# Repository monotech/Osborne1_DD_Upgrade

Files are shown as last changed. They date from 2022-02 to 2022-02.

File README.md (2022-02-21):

# Osborne1_DD_Upgrade
Exact replica of the Double Density floppy upgrade board for the Osborne 1

Every part except the PCB can be bought from proper distributors such as Mouser, Digikey, Farnell/element14, LCSC, etc. Avoid chips from Aliexpress/eBay.

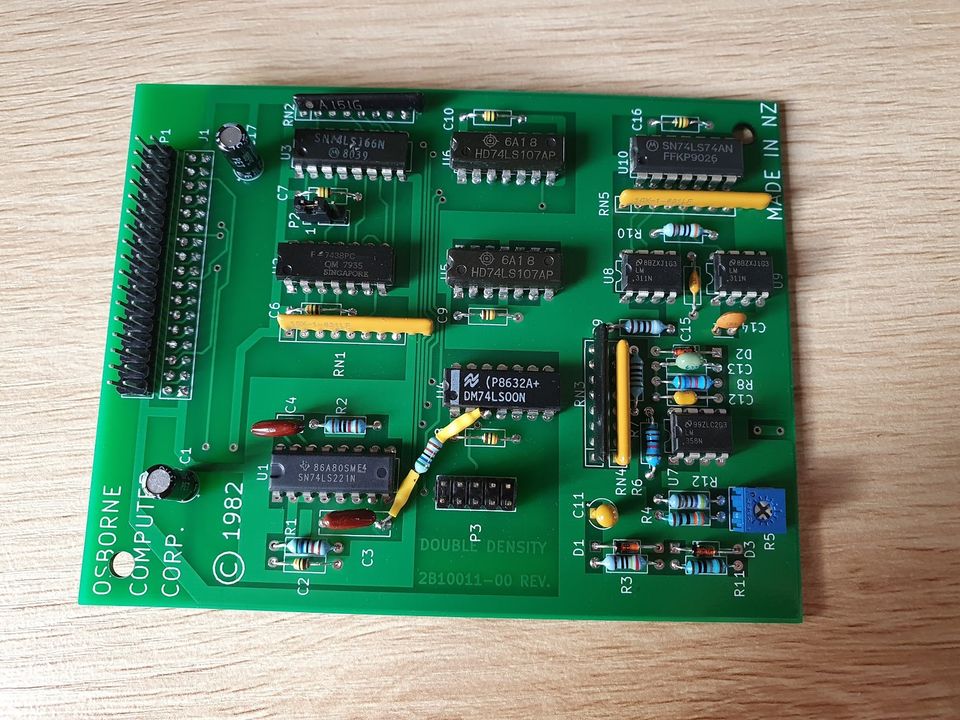
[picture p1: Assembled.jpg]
assembled


Licensed under CC BY-SA 4.0 (https://creativecommons.org/licenses/by-sa/4.0/)

You can share, change, sell, but you must give credit and provide your adaptations under the same license.

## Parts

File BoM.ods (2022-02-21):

Designator | Quantity | Part | Package | Notes
 | 1 | PCB
 | 1 | 2x5 2.54mm IDC cable | 18cm
 | 1 | 2.54mm jumper shunt
P1 | 1 | 2x17 2.54mm male header
J1 | 1 | 2x17 2.54mm female header
P2 | 1 | 1x3 2.54mm male header
P3 | 1 | 2x5 2.54mm male header
C1 | 1 | 22uF 16V Electrolytic | 2.54mm
C17 | 1 | 47uF 16V Electrolytic | 2.54mm
C11 | 1 | 1uF 16V Tantalum | 2.54mm
C12 | 1 | 330pF ceramic capacitor | 10.16mm axial
C13 | 1 | 3.3nF ceramic capacitor | 10.16mm axial
C15 | 1 | 100nF ceramic capacitor | 10.16mm axial
C14 | 1 | 47pF ceramic capacitor | 2.54mm
C3-4 | 2 | 47pF 2% mica capacitor | 2.54mm
C2,C6-10,C16 | 7 | 10nF ceramic capacitor | 10.16mm axial
D1 | 1 | 1N5231B | 10.16mm axial
D2 | 1 | 1N5228B | 10.16mm axial
D3 | 1 | 1N5238 | 10.16mm axial
RN1,RN5 | 2 | 820R 7-way bussed resistor network | SIP-8
RN2 | 1 | 150R 7-way bussed resistor network | SIP-8 | SIP-5 is fine also
RN3 | 1 | 4.7k 7-way bussed resistor network | SIP-8 | SIP-5 is fine also
RN4 | 1 | 39k 4-way isolated resistor pack | SIP-8
R1,bodge1 | 2 | 56.2k 1% resistor | 10.16mm axial
bodge2 | 1 | 1M resistor
R2 | 1 | 10k 1% resistor | 10.16mm axial
R3 | 1 | 240R resistor | 10.16mm axial
R4 | 1 | 330R 1% resistor | 10.16mm axial
R5 | 1 | 10k trimpot | T73YP
R6 | 1 | 11k resistor | 10.16mm axial
R7 | 1 | 510R resistor | 10.16mm axial
R8 | 1 | 16k resistor | 10.16mm axial
R9 | 1 | 9.1k 2% resistor | 10.16mm axial
R10 | 1 | 3.01k 1% resistor | 10.16mm axial
R11 | 1 | 180R resistor | 10.16mm axial
R12 | 1 | 4.7k 2% resistor | 10.16mm axial
U1 | 1 | 74LS221 IC | DIP-16
U2 | 1 | 7438 IC | DIP-14
U3 | 1 | 74LS166 IC | DIP-16
U4 | 1 | 74LS00 IC | DIP-14
U5-6 | 2 | 74LS107 IC | DIP-14
U7 | 1 | LM358 IC | DIP-8
U8-9 | 2 | LM311 IC | DIP-8
U10 | 1 | 74LS74 IC | DIP-14
 |  |  | TP9 is U7 Pin7.

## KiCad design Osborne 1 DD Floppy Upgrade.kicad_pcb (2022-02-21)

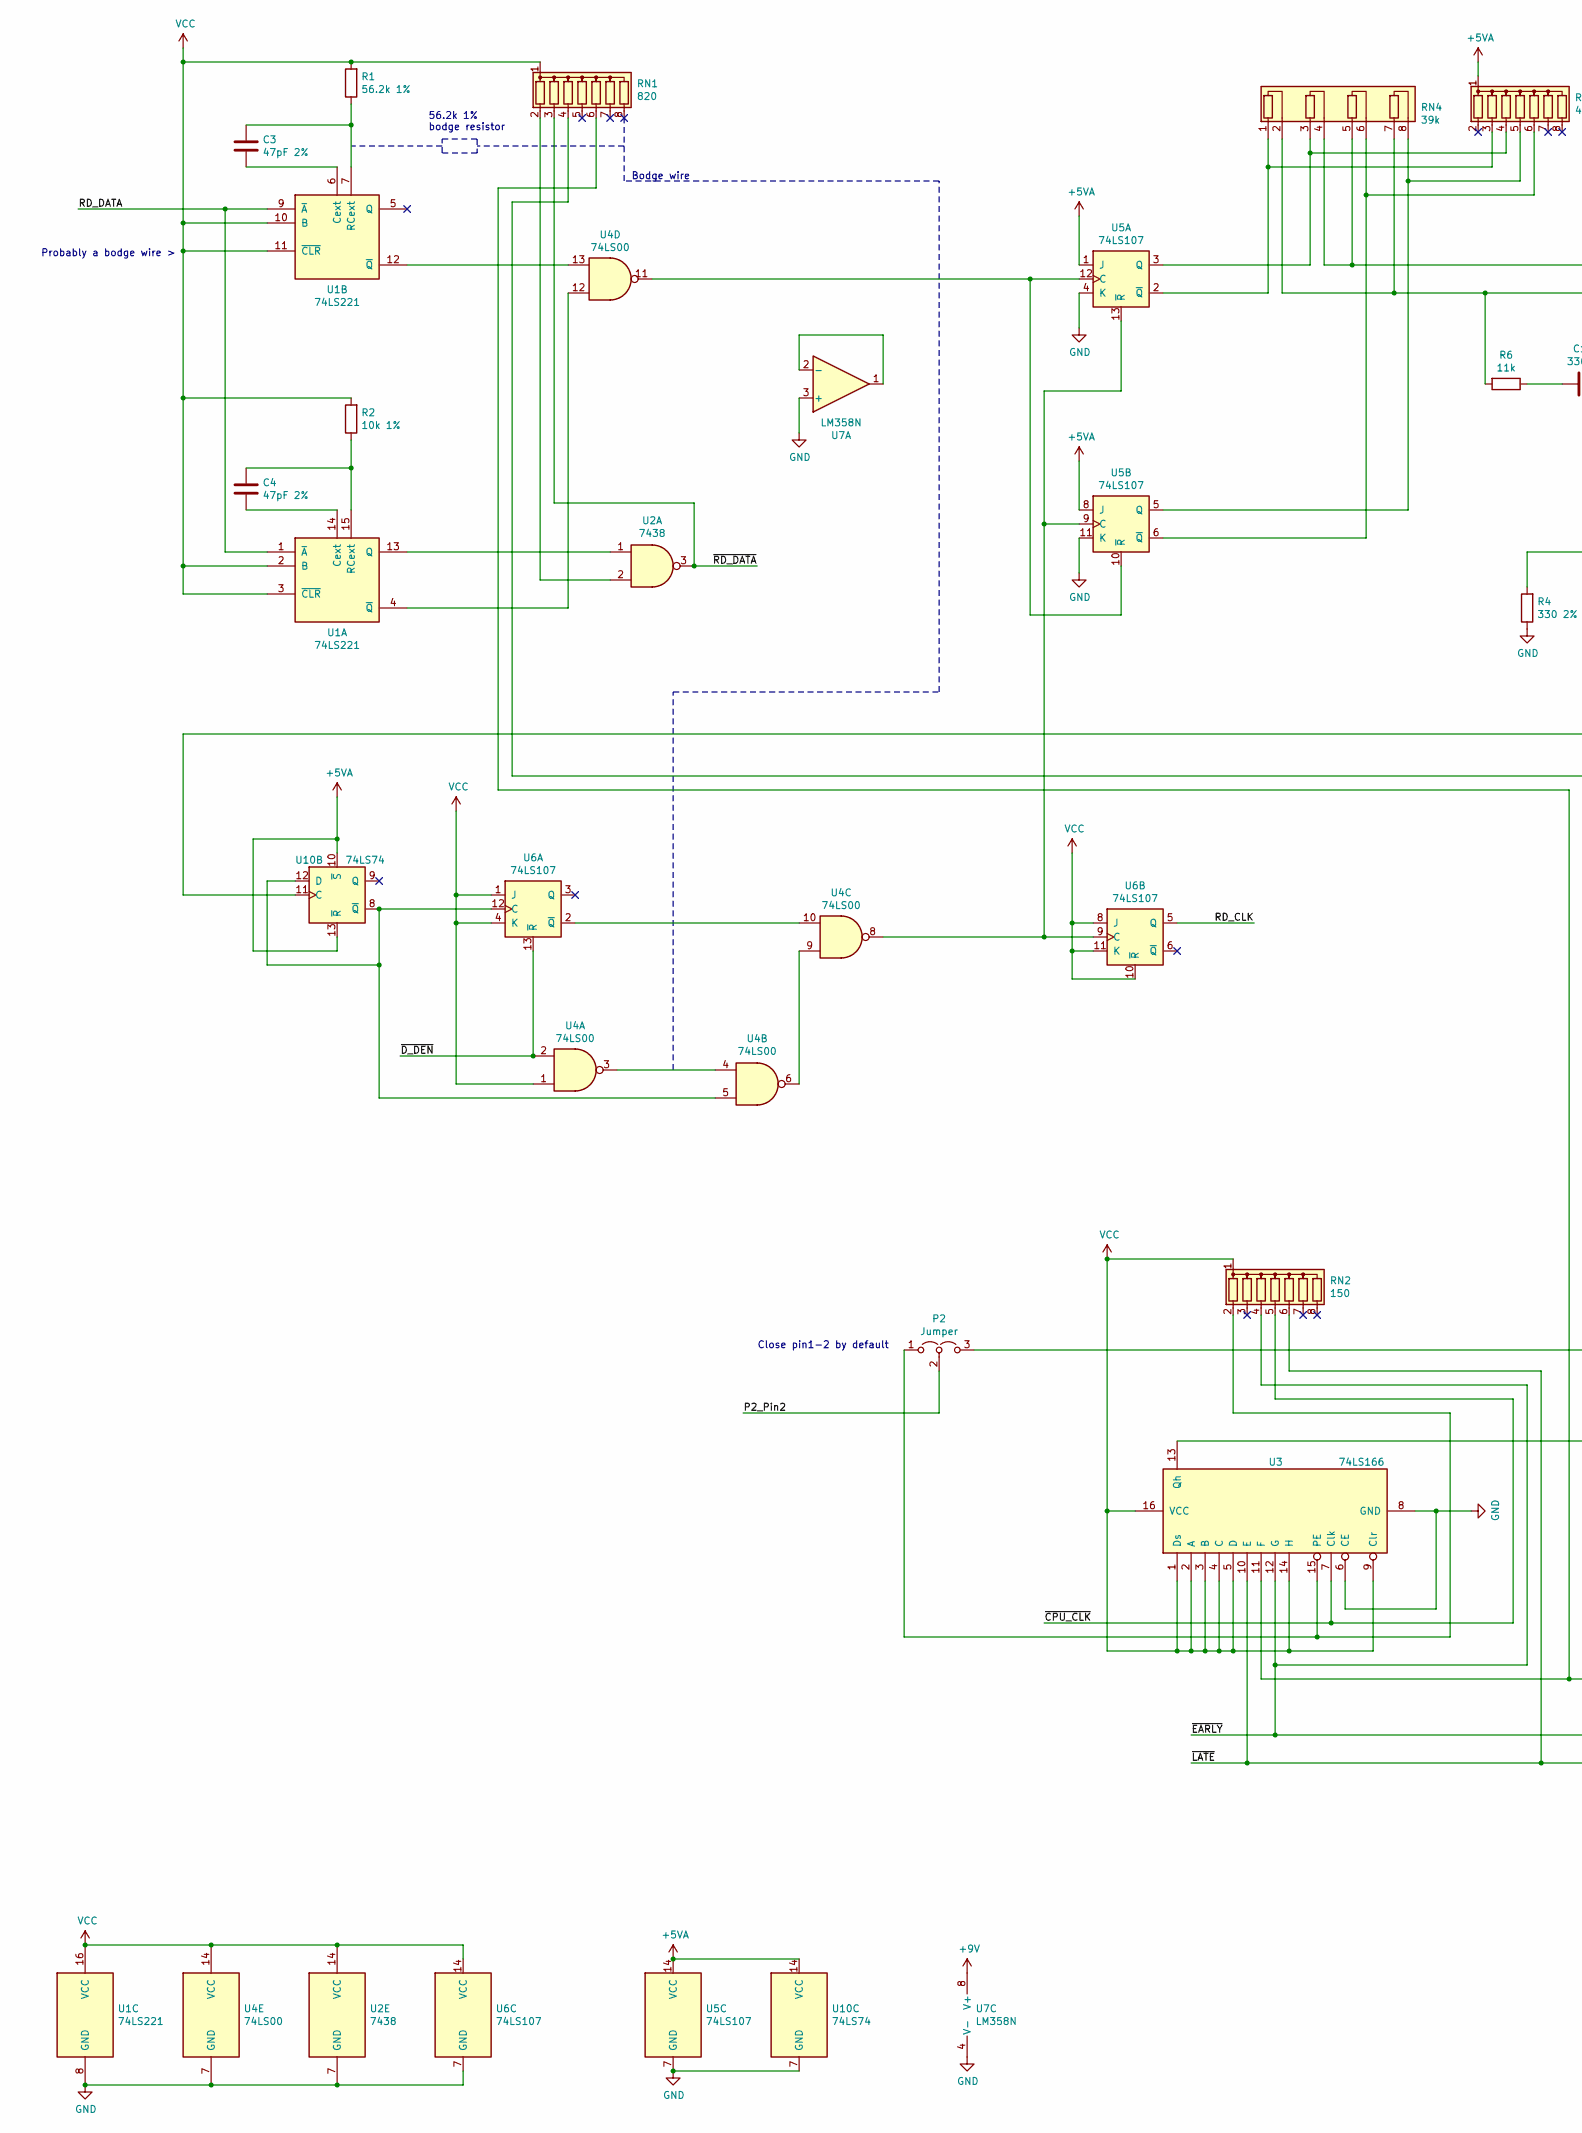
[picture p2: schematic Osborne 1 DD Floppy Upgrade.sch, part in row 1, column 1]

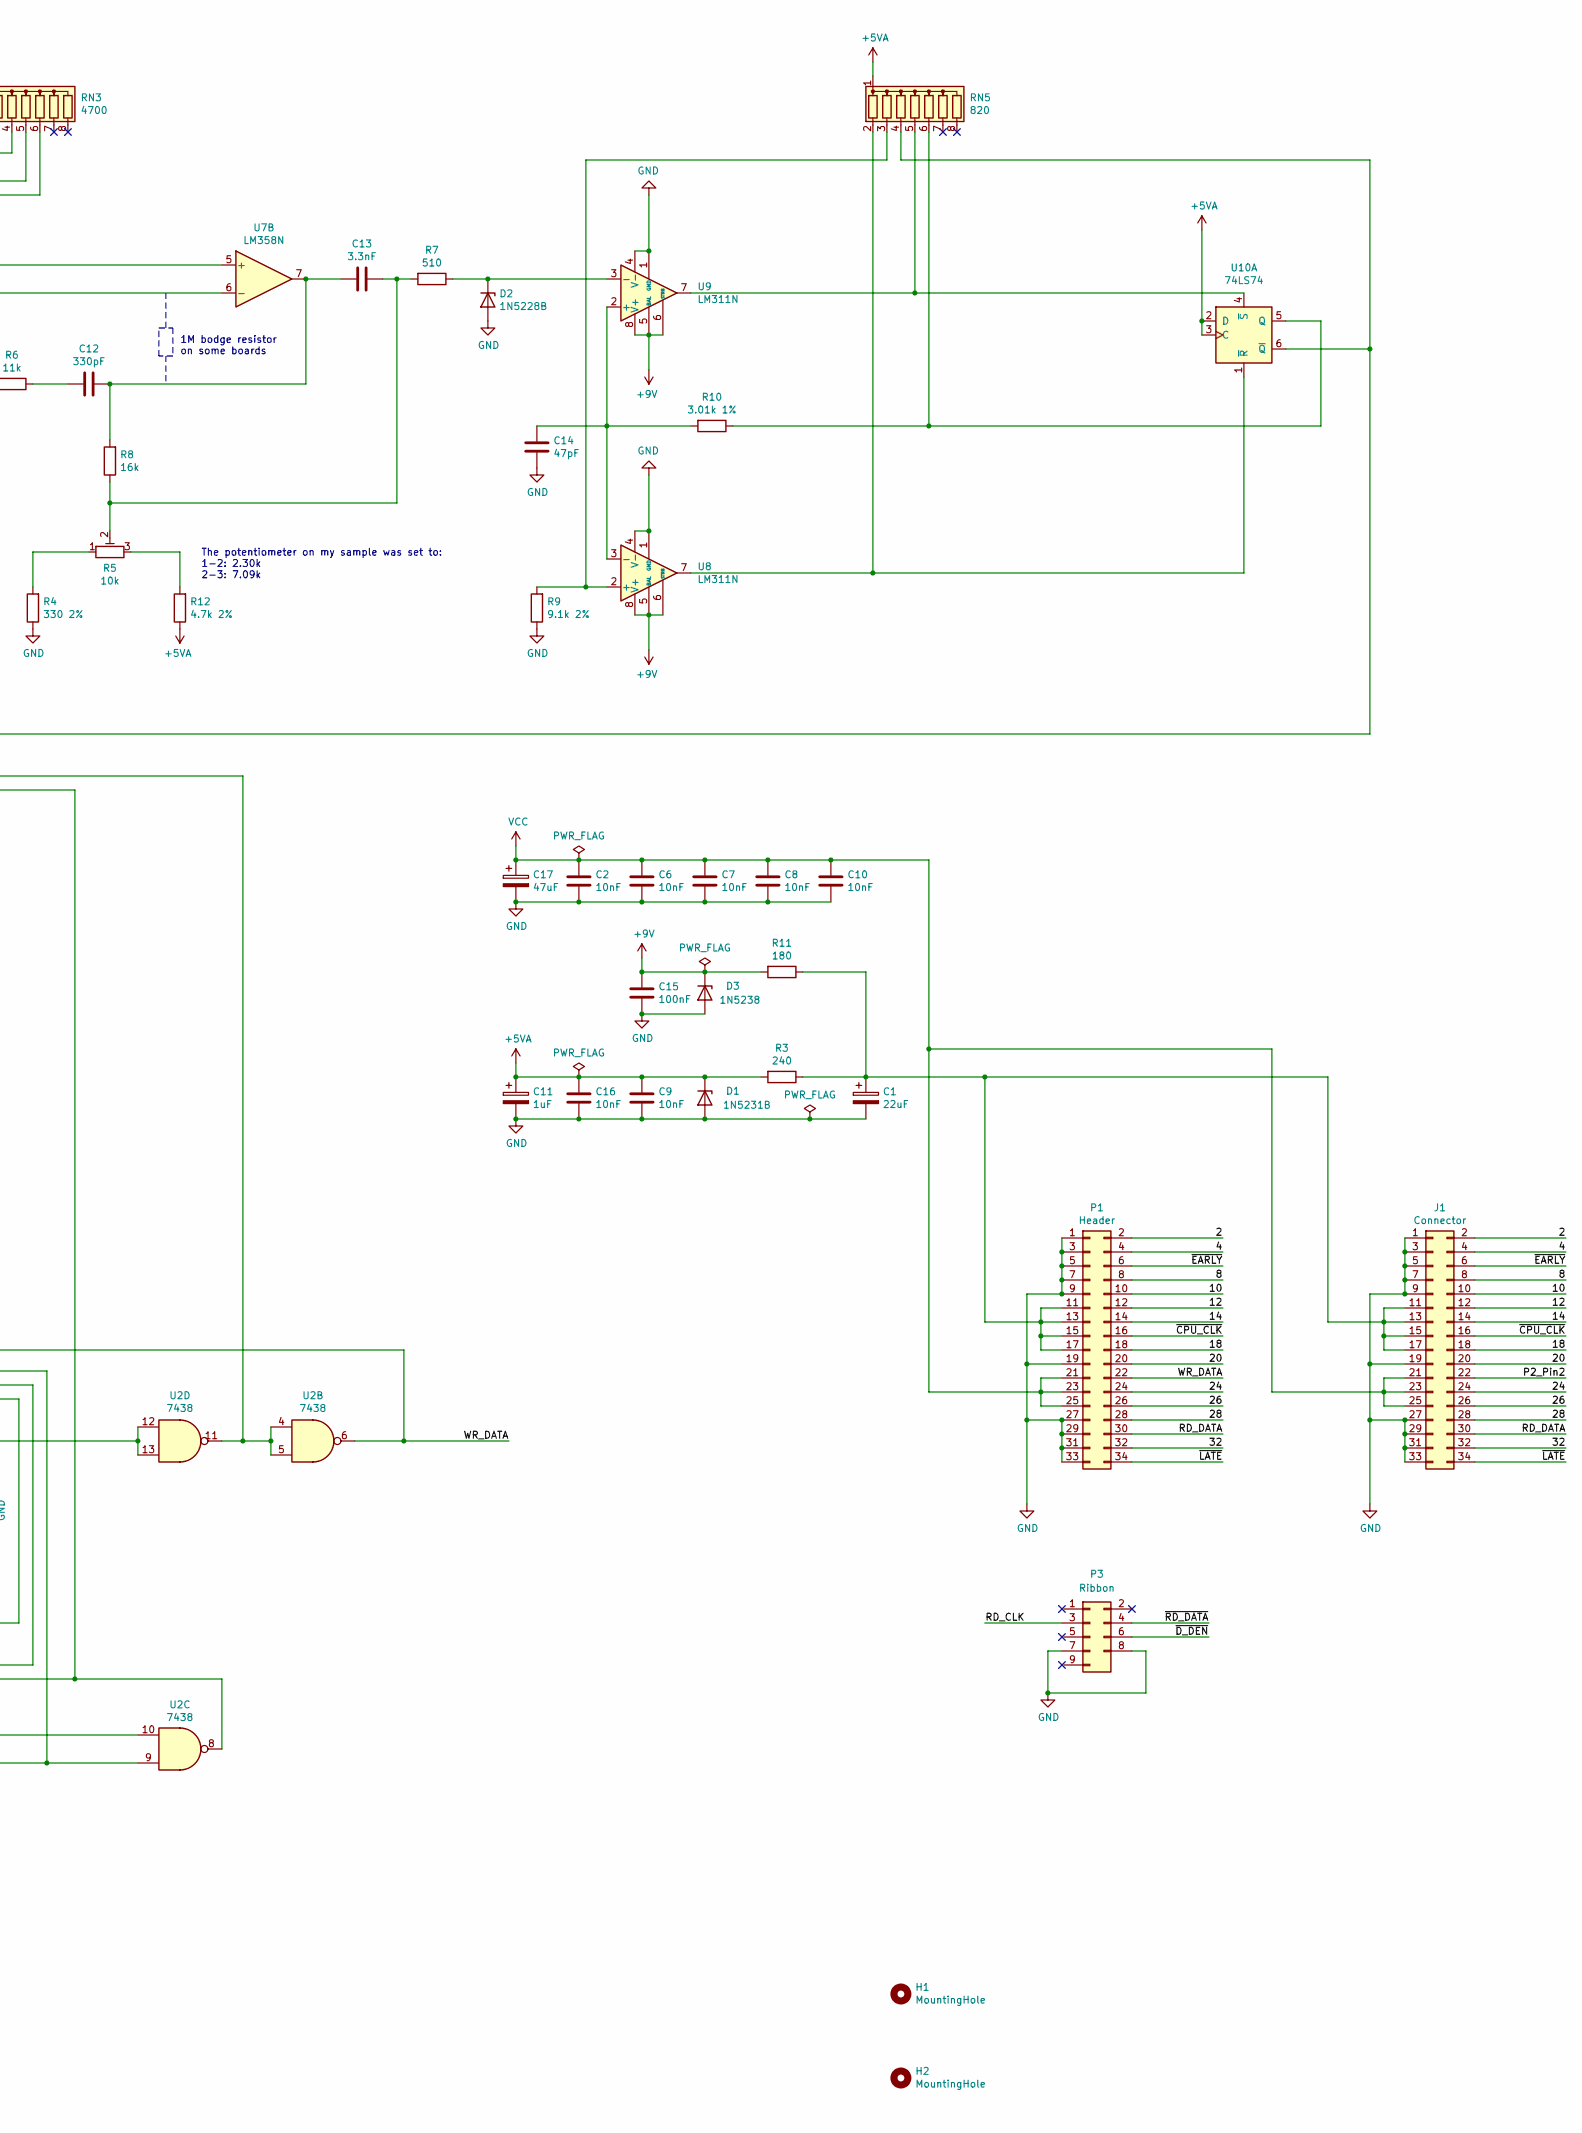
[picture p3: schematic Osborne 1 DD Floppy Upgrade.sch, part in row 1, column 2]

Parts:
C1: 22uF; CP_Radial_D5.0mm_P2.50mm
C2, C6, C7, C8, C9, C10, C16: 10nF; R_Axial_DIN0207_L6.3mm_D2.5mm_P10.16mm_Horizontal
C3: 47pF 2%; C_Rect_L11.0mm_W3.5mm_P10.00mm_MKT
C4: 47pF 2%; C_Rect_L4.0mm_W2.5mm_P2.50mm
C11: 1uF; CP_Radial_Tantal_D4.5mm_P2.50mm
C12: 330pF; R_Axial_DIN0207_L6.3mm_D2.5mm_P10.16mm_Horizontal
C13: 3.3nF; R_Axial_DIN0207_L6.3mm_D2.5mm_P10.16mm_Horizontal
C14: 47pF; C_Disc_D3.0mm_W2.0mm_P2.50mm
C15: 100nF; R_Axial_DIN0207_L6.3mm_D2.5mm_P10.16mm_Horizontal
C17: 47uF; CP_Radial_D5.0mm_P2.50mm
D1: 1N5231B; D_DO-35_SOD27_P10.16mm_Horizontal
D2: 1N5228B; D_DO-35_SOD27_P10.16mm_Horizontal
D3: 1N5238; D_DO-35_SOD27_P10.16mm_Horizontal
H1, H2: MountingHole; MountingHole_4mm
J1: Connector; PinHeader_2x17_P2.54mm_Vertical
P1: Header; PinHeader_2x17_P2.54mm_Vertical
P2: Jumper; PinHeader_1x03_P2.54mm_Vertical
P3: Ribbon; PinHeader_2x05_P2.54mm_Vertical
R1: 56.2k 1%; R_Axial_DIN0207_L6.3mm_D2.5mm_P10.16mm_Horizontal
R2: 10k 1%; R_Axial_DIN0207_L6.3mm_D2.5mm_P10.16mm_Horizontal
R3: 240; R_Axial_DIN0207_L6.3mm_D2.5mm_P10.16mm_Horizontal
R4: 330 2%; R_Axial_DIN0207_L6.3mm_D2.5mm_P10.16mm_Horizontal
R5: 10k; Potentiometer_Vishay_T73YP_Vertical
R6: 11k; R_Axial_DIN0207_L6.3mm_D2.5mm_P10.16mm_Horizontal
R7: 510; R_Axial_DIN0207_L6.3mm_D2.5mm_P10.16mm_Horizontal
R8: 16k; R_Axial_DIN0207_L6.3mm_D2.5mm_P10.16mm_Horizontal
R9: 9.1k 2%; R_Axial_DIN0207_L6.3mm_D2.5mm_P10.16mm_Horizontal
R10: 3.01k 1%; R_Axial_DIN0207_L6.3mm_D2.5mm_P10.16mm_Horizontal
R11: 180; R_Axial_DIN0207_L6.3mm_D2.5mm_P10.16mm_Horizontal
R12: 4.7k 2%; R_Axial_DIN0207_L6.3mm_D2.5mm_P10.16mm_Horizontal
RN1, RN5: 820; R_Array_SIP8
RN2: 150; R_Array_SIP8
RN3: 4700; R_Array_SIP8
RN4: 39k; R_Array_SIP8
U1: 74LS221; DIP-16_W7.62mm
U2: 7438; DIP-14_W7.62mm
U3: 74LS166; DIP-16_W7.62mm
U4: 74LS00; DIP-14_W7.62mm
U5, U6: 74LS107; DIP-14_W7.62mm
U7: LM358N; DIP-8_W7.62mm
U8, U9: LM311N; DIP-8_W7.62mm
U10: 74LS74; DIP-14_W7.62mm

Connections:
+5VA: C9.1, C11.1, C16.1, D1.1 (K), R3.2, R12.1, RN3.1 (common), RN5.1 (common), U5.1 (J), U5.8 (J), U5.14 (VCC), U10.2 (D), U10.3 (C), U10.10 (~S), U10.13 (~R), U10.14 (VCC)
+9V: C15.1, D3.1 (K), R11.2, U7.8 (V+), U8.5 (BAL), U8.6 (STRB), U8.8 (V+), U9.5 (BAL), U9.6 (STRB), U9.8 (V+)
/2: J1.2, P1.2
/4: J1.4, P1.4
/8: J1.8, P1.8
/10: J1.10, P1.10
/12: J1.12, P1.12
/14: J1.14, P1.14
/18: J1.18, P1.18
/20: J1.20, P1.20
/24: J1.24, P1.24
/26: J1.26, P1.26
/28: J1.28, P1.28
/32: J1.32, P1.32
/P2_Pin2: J1.22, P2.2 (C)
/RD_CLK: P3.3, U6.5 (Q)
/RD_DATA: J1.30, P1.30, U1.1 (~A), U1.9 (~A)
/WR_DATA: P1.22, P2.3 (B), U2.6
/~CPU_CLK: J1.16, P1.16, RN2.5 (R4), U3.7 (Clk)
/~D_DEN: P3.6, U4.2, U6.13 (~R)
/~EARLY: J1.6, P1.6, RN2.4 (R3), U2.10, U3.12 (G)
/~LATE: J1.34, P1.34, RN2.6 (R5), U2.9, U3.10 (E)
/~RD_DATA: P3.4, RN1.3 (R2), U2.3
GND: C1.2, C2.2, C6.2, C7.2, C8.2, C9.2, C10.2, C11.2, C14.2, C15.2, C16.2, C17.2, D1.2 (A), D2.2 (A), D3.2 (A), J1.1, J1.3, J1.5, J1.7, J1.9, J1.19, J1.27, J1.29, J1.31, J1.33, P1.1, P1.3, P1.5, P1.7, P1.9, P1.19, P1.27, P1.29, P1.31, P1.33, P3.7, P3.8, R4.1, R9.1, U1.8 (GND), U2.7 (GND), U3.6 (CE), U3.8 (GND), U4.7 (GND), U5.4 (K), U5.7 (GND), U5.11 (K), U6.7 (GND), U7.3 (+), U7.4 (V-), U8.1 (GND), U8.4 (V-), U9.1 (GND), U9.4 (V-), U10.7 (GND)
unnamed: C1.1, J1.11, J1.13, J1.15, J1.17, P1.11, P1.13, P1.15, P1.17, R3.1, R11.1
unnamed: C3.1, R1.1, U1.7 (RCext)
unnamed: C3.2, U1.6 (Cext)
unnamed: C4.1, R2.1, U1.15 (RCext)
unnamed: C4.2, U1.14 (Cext)
unnamed: C12.1, C13.2, R8.2, U7.7
unnamed: C12.2, R6.1
unnamed: C13.1, R5.2, R7.2, R8.1
unnamed: C14.1, R10.2, U8.3 (-), U9.2 (+)
unnamed: D2.1 (K), R7.1, U9.3 (-)
unnamed: P2.1 (A), RN2.2 (R1), U3.15 (PE)
unnamed: R4.2, R5.1
unnamed: R6.2, RN4.2 (R1.2), RN4.7 (R4.1), U7.6 (-)
unnamed: R9.2, RN5.3 (R2), U8.2 (+)
unnamed: R10.1, RN5.6 (R5), U10.5 (Q)
unnamed: R5.3, R12.2
unnamed: RN1.2 (R1), U2.2
unnamed: RN1.4 (R3), U2.4, U2.5, U2.11
unnamed: RN1.6 (R5), U2.8, U3.11 (F)
unnamed: RN3.3 (R2), RN4.1 (R1.1), U5.2 (~Q)
unnamed: RN3.4 (R3), RN4.3 (R2.1), U5.3 (Q)
unnamed: RN3.5 (R4), RN4.8 (R4.2), U5.5 (Q)
unnamed: RN3.6 (R5), RN4.6 (R3.2), U5.6 (~Q)
unnamed: RN4.4 (R2.2), RN4.5 (R3.1), U7.5 (+)
unnamed: RN5.2 (R1), U8.7, U10.1 (~R)
unnamed: RN5.4 (R3), U10.6 (~Q), U10.11 (C)
unnamed: RN5.5 (R4), U9.7, U10.4 (~S)
unnamed: U1.4 (~Q), U4.12
unnamed: U1.12 (~Q), U4.13
unnamed: U1.13 (Q), U2.1
unnamed: U2.12, U2.13, U3.13 (Qh)
unnamed: U4.3, U4.4
unnamed: U4.6, U4.9
unnamed: U4.8, U5.9 (C), U5.13 (~R), U6.9 (C)
unnamed: U4.10, U6.2 (~Q)
unnamed: U4.11, U5.10 (~R), U5.12 (C)
unnamed: U7.1, U7.2 (-)
unnamed: U4.5, U6.12 (C), U10.8 (~Q), U10.12 (D)
VCC: C2.1, C6.1, C7.1, C8.1, C10.1, C17.1, J1.21, J1.23, J1.25, P1.21, P1.23, P1.25, R1.2, R2.2, RN1.1 (common), RN2.1 (common), U1.2 (B), U1.3 (~CLR), U1.10 (B), U1.11 (~CLR), U1.16 (VCC), U2.14 (VCC), U3.1 (Ds), U3.2 (A), U3.3 (B), U3.4 (C), U3.5 (D), U3.9 (Clr), U3.14 (H), U3.16 (VCC), U4.1, U4.14 (VCC), U6.1 (J), U6.4 (K), U6.8 (J), U6.10 (~R), U6.11 (K), U6.14 (VCC)

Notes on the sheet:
56.2k 1% bodge resistor
Close pin1-2 by default
Bodge wire
1M bodge resistor on some boards
Probably a bodge wire >
The potentiometer on my sample was set to: 1-2: 2.30k 2-3: 7.09k

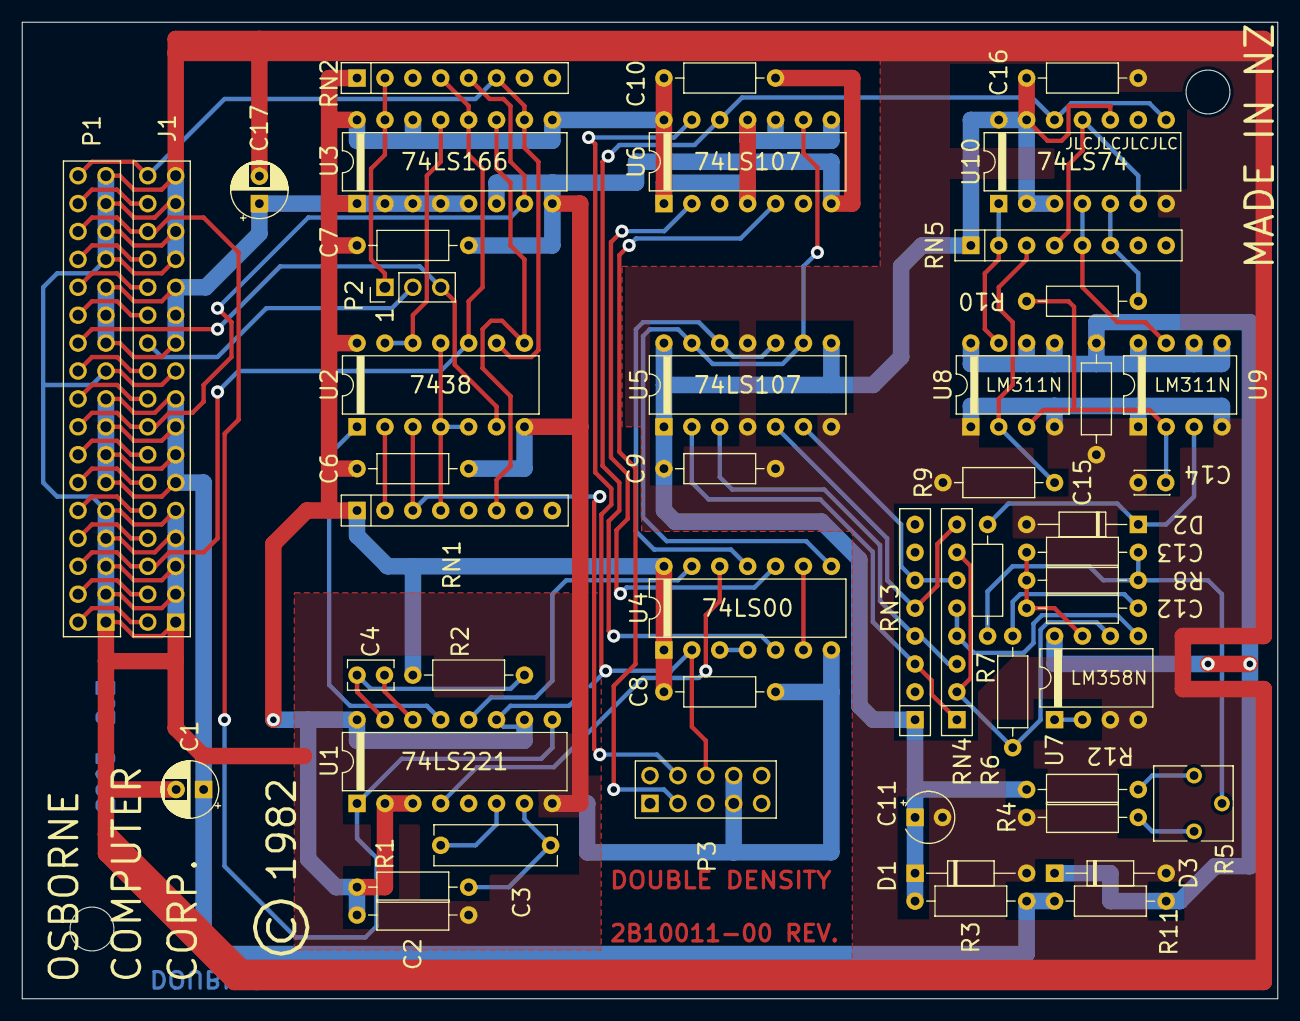
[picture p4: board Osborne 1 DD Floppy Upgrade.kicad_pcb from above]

Board: 2 copper layers, 114.3 x 88.9 mm, 52 parts (0 on the bottom side), 63 nets.
